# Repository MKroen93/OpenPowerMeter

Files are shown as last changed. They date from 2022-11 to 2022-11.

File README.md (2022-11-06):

# OpenPowerMeter
An open source power meter design including hardware and software

This is an open source power meter design. It is compatible with the **YHDC SCT-013-000** current clamp to measure AC mains current without contact. Optionally, 3 phase mains voltage can be measured by connecting it to the bottom screw terminal. The PCB is designed to fit into the Bopla CNC 87.5 DIN rail casing and consists on a lower and upper half of hardware which fit together through 2.54 mm pinheaders.

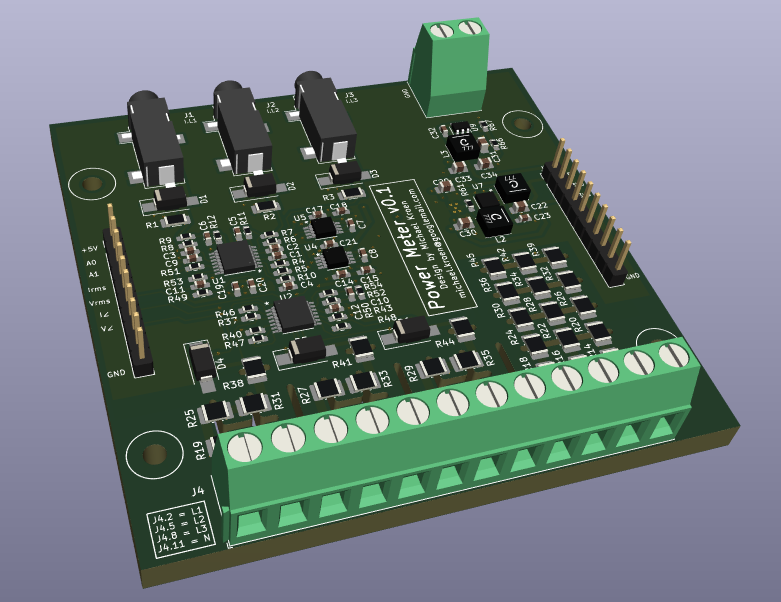
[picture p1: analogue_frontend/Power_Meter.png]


The lower part contains the analog frontend for converting the input signals to true rms values and for converting the input waveforms to a rectangular 3.3V output signal which can be used to detect the phase using a simple timer.

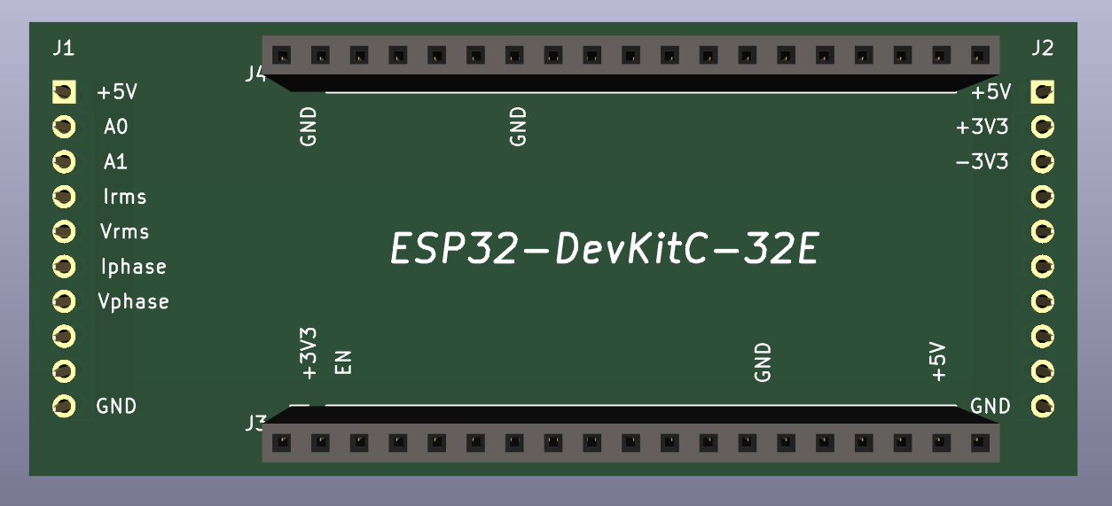
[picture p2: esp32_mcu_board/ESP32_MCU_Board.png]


The upper part contains the MCU (ESP32) and ADC and is not yet finished.

**Please note:** This project is currently in early development and not yet tested or ready to be used.

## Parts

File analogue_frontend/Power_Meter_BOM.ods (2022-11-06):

C:\Users\Michael\Documents\KiCAD\Power_Meter\Power_Meter.kicad_sch
05.11.2022 15:04:58
Eeschema (6.0.8)
C:\Program Files\KiCad\6.0\bin\scripting\plugins/bom_csv_grouped_by_value.py
132
Qty | Reference(s) | Value | LibPart | Footprint | Grade | Part nr. | Voltage rating
16 | C1 C2 C3 C9 C10 C13 C14 C15 C16 C17 C18 C19 C20 C21 C23 C32 | 100n | Device:C | 0603 | X7R |  | 10V
3 | C4 C5 C6 | 1n | Device:C | 0603 | X7R |  | 6.3V
4 | C7 C8 C11 C12 | 1µ | Device:C | 0603 | X7R |  | 6.3V
3 | C22 C29 C30 | 10µ | Device:C | 0805 | X7R |  | 10V
4 | C24 C25 C33 C34 | 22µ | Device:C | 0805 | X7R |  | 10V
3 | C26 C27 C28 | 10n | Device:C | 0603 | X7R |  | 10V
1 | C31 | 2µ2 | Device:C | 0805 |  |  | 35V
1 | C35 | 10µ | Device:C | 0805 | X5R |  | 35V
6 | D1 D2 D3 D4 D5 D6 | SMAJ5.0CA | Device:D_TVS | SMA
2 | D7 D8 | BAT54J | Diode:BAT54J | Diode_SMD:D_SOD-323F
1 | D9 | MM5Z6V8T1G | Diode:MM5Zxx | Diode_SMD:D_SOD-523
3 | J1 J2 J3 | AudioJack3 | Connector:AudioJack3 | Footprints:Jack_3.5mm_CUI_SJ-3523-SMT_Horizontal
1 | J4 | Screw_Terminal_01x12 | Connector:Screw_Terminal_01x12 | TerminalBlock_Phoenix:TerminalBlock_Phoenix_MKDS-1,5-12-5.08_1x12_P5.08mm_Horizontal
1 | J5 | Screw_Terminal_01x02 | Connector:Screw_Terminal_01x02 | TerminalBlock_Phoenix:TerminalBlock_Phoenix_MKDS-1,5-2-5.08_1x02_P5.08mm_Horizontal
2 | J6 J7 | Conn_01x10 | Connector_Generic:Conn_01x10 | Connector_PinHeader_2.54mm:PinHeader_1x10_P2.54mm_Vertical
2 | L1 L2 | 4µ7 | Device:L | Footprints:L_Coilcraft_XxL4020 |  | XFL4020-472ME_
1 | L3 | 10µ | Device:L | Footprints:L_Coilcraft_XxL4020 |  | XAL4040-103ME_
1 | Q1 | SISS73DN | SISS73DN:SISS73DN | Footprints:Vishay_PowerPAK_1212-8_Single
3 | R1,R2,R3 | 20 | Device:R | 1206
3 | R4 R6 R8 | 22k | Device:R | 0603
8 | R5 R7 R9 R10 R11 R12 R56 R59 | 47k | Device:R | 0603
30 | R13 R14 R15 R16 R17 R18 R19 R20 R21 R22 R23 R24 R25 R26 R27 R28 R29 R30 R31 R32 R33 R34 R35 R36 R38 R39 R41 R42 R44 R45 | 976k | Device:R | 1210
6 | R37 R40 R43 R46 R47 R48 | 15k | Device:R | 0603
2 | R49 R50 | 38k3 | Device:R | 0603
2 | R51 R52 | 169k | Device:R | 0603
2 | R53 R54 | 294k | Device:R | 0603
2 | R55 R58 | 1k | Device:R | 0603
2 | R57 R60 | 3k3 | Device:R | 0603
3 | R61 R63 R65 | 10k | Device:R | 0603
1 | R62 | 17k8 | Device:R | 0603
1 | R64 | 28k | Device:R | 0603
1 | R66 | 100k | Device:R | 0603
1 | R67 | 13k7 | Device:R | 0603
1 | R68 | 4k7 | Device:R | 0603
2 | U1 U2 | ADA4851-4 | ADA4851-4_multipart:ADA4851-4 | Footprints:ADA4851-4YRUZ
1 | U3 | ADG659 | ADG659_multipart:ADG659 | Footprints:ADG659YRUZ
2 | U4 U5 | LTC1966CMS8 | LTC1966:LTC1966CMS8 | Footprints:LTC1966CMS8
1 | U6 | ADA4851-2 | ADA4851-2_multipart:ADA4851-2 | Footprints:ADA4851-2YRMZ
1 | U7 | TPS65133DPDR | TPS65133:TPS65133DPDR | Footprints:TPS65133DPDR
1 | U8 | TPS7A3901DSCR | TPS7A39:TPS7A3901DSCR | Footprints:TPS7A3901DSCR
1 | U9 | PLMR51420XDDCR | LMR51420:PLMR51420XDDCT | Footprints:PLMR51420XDDCT
132

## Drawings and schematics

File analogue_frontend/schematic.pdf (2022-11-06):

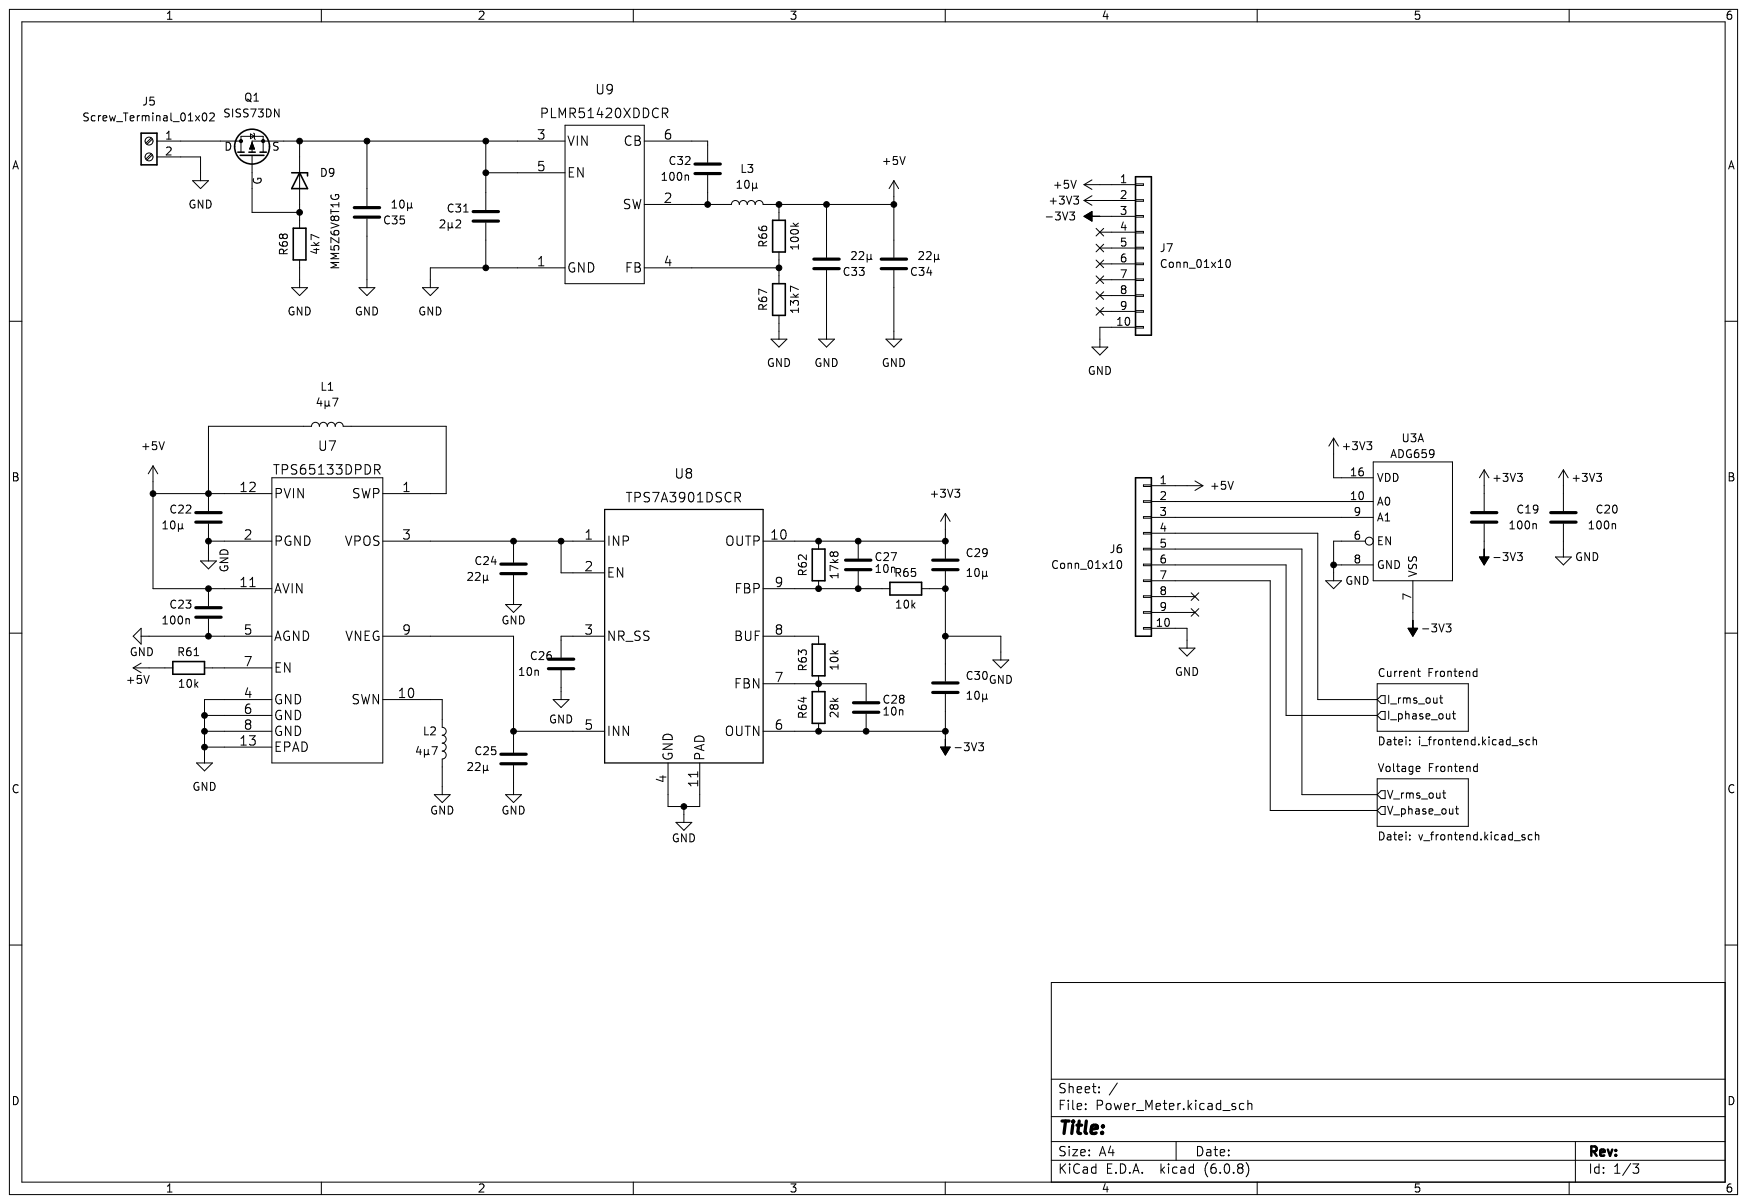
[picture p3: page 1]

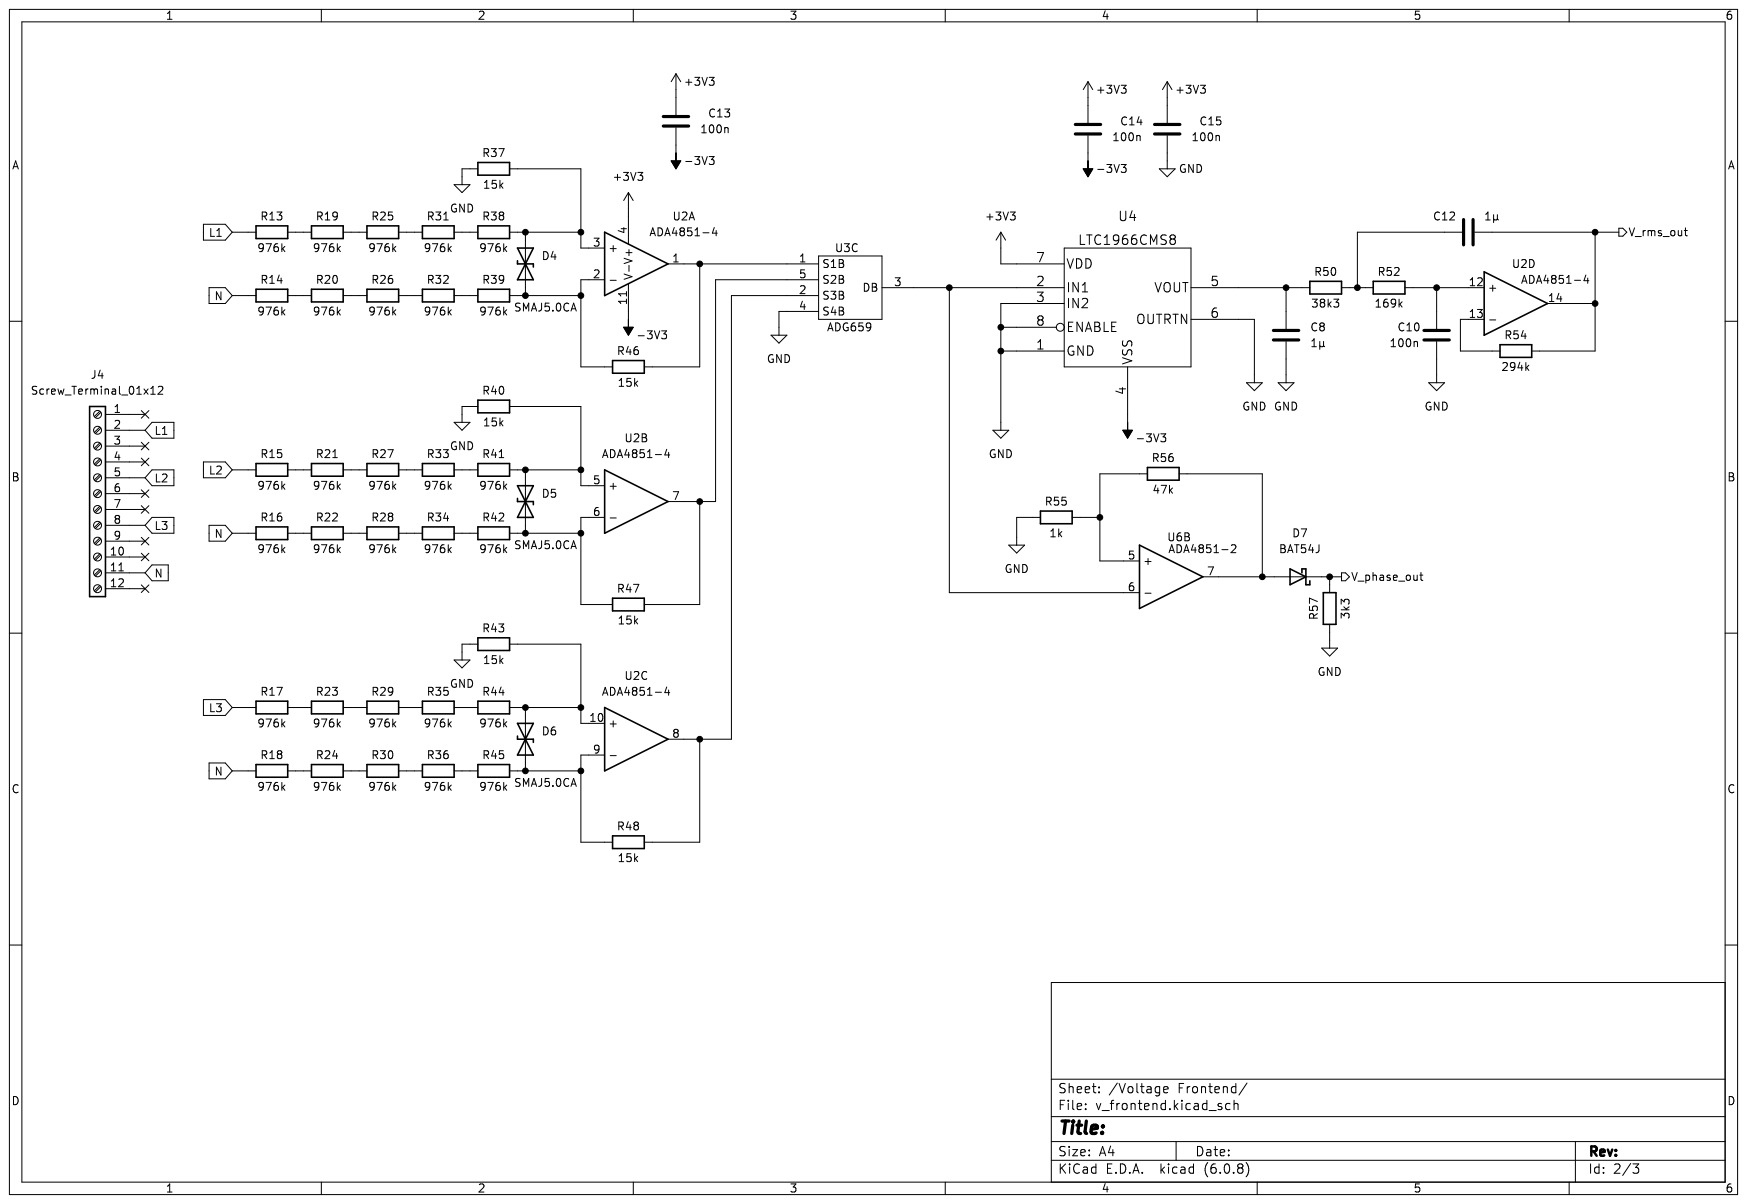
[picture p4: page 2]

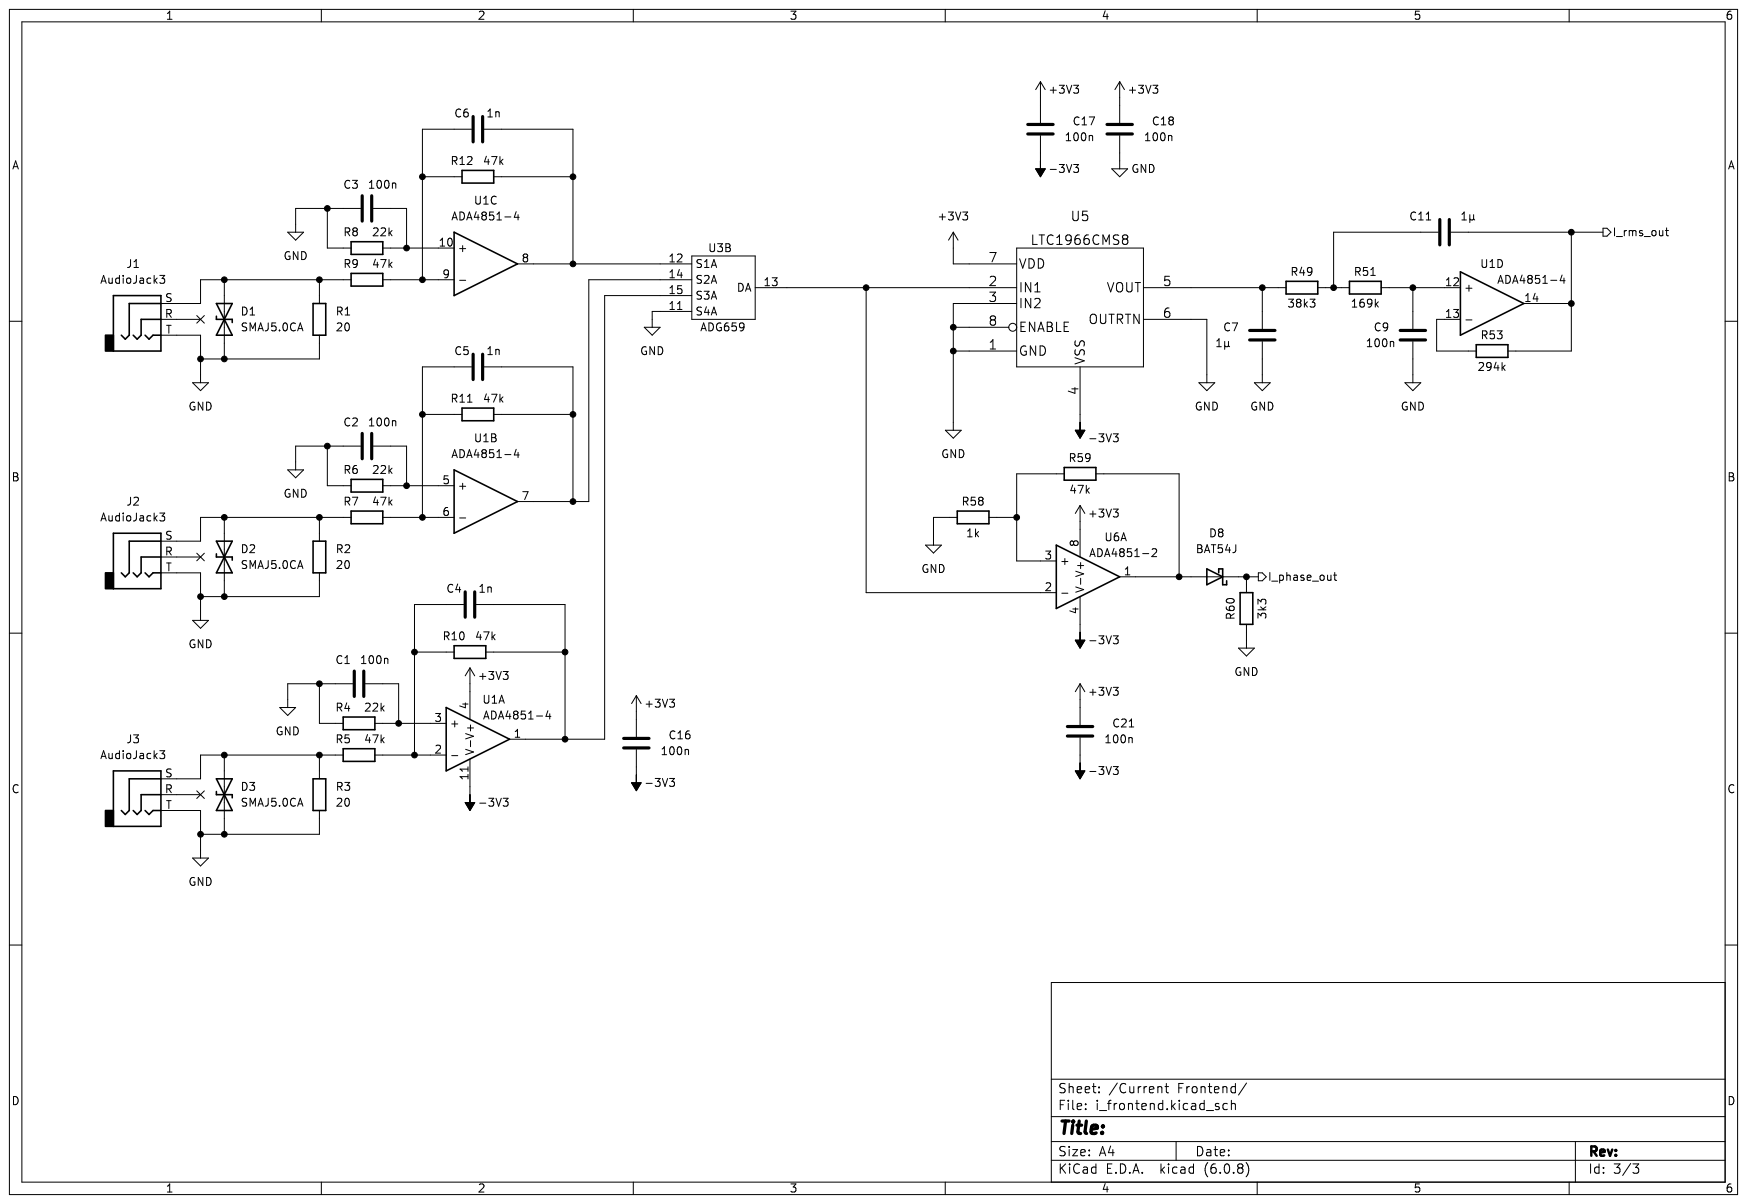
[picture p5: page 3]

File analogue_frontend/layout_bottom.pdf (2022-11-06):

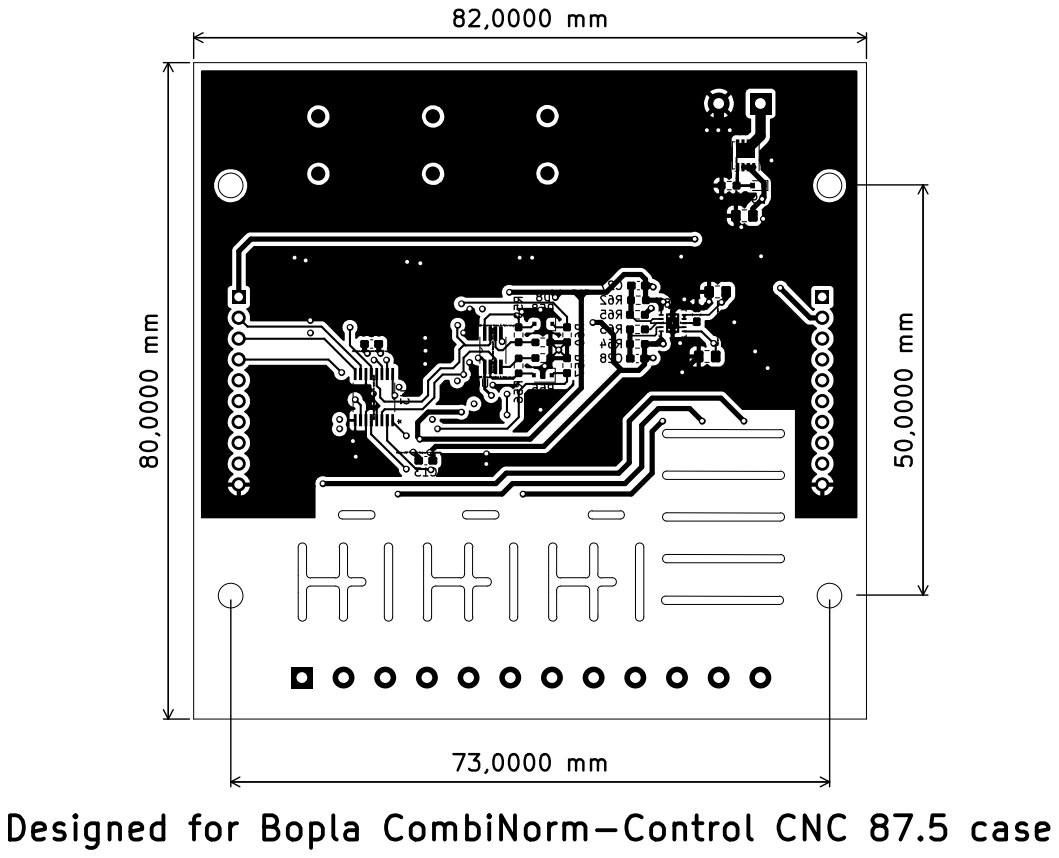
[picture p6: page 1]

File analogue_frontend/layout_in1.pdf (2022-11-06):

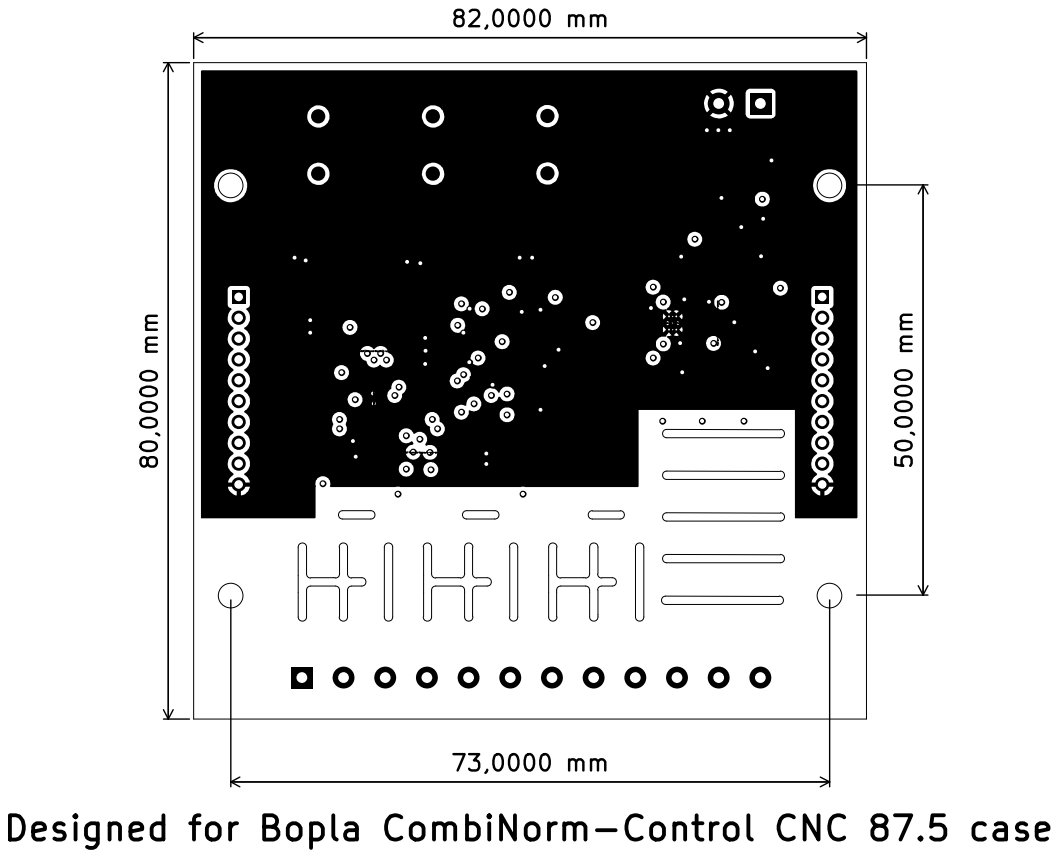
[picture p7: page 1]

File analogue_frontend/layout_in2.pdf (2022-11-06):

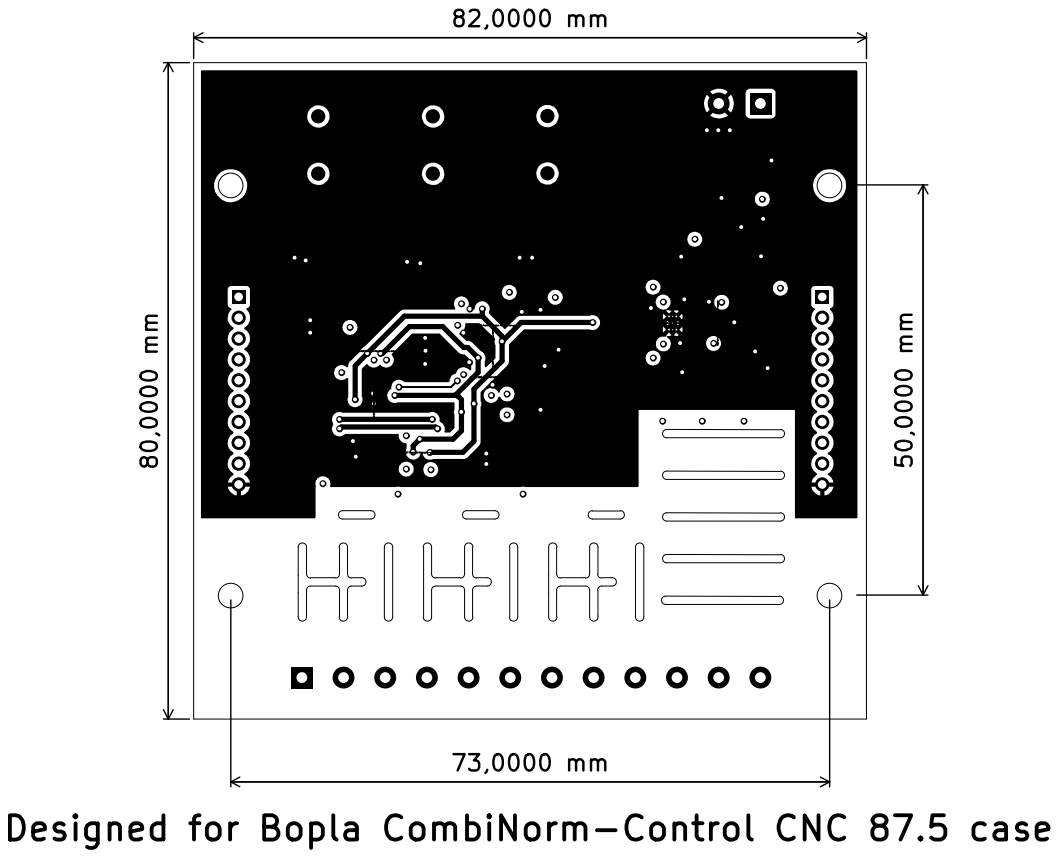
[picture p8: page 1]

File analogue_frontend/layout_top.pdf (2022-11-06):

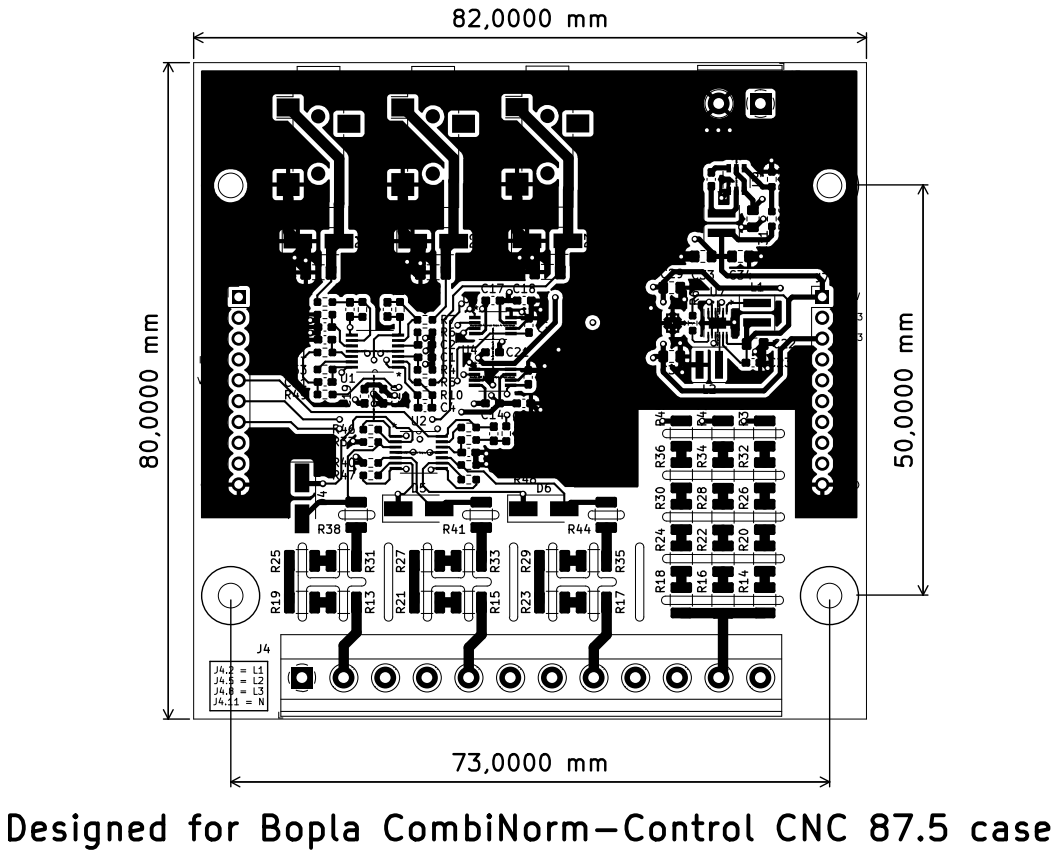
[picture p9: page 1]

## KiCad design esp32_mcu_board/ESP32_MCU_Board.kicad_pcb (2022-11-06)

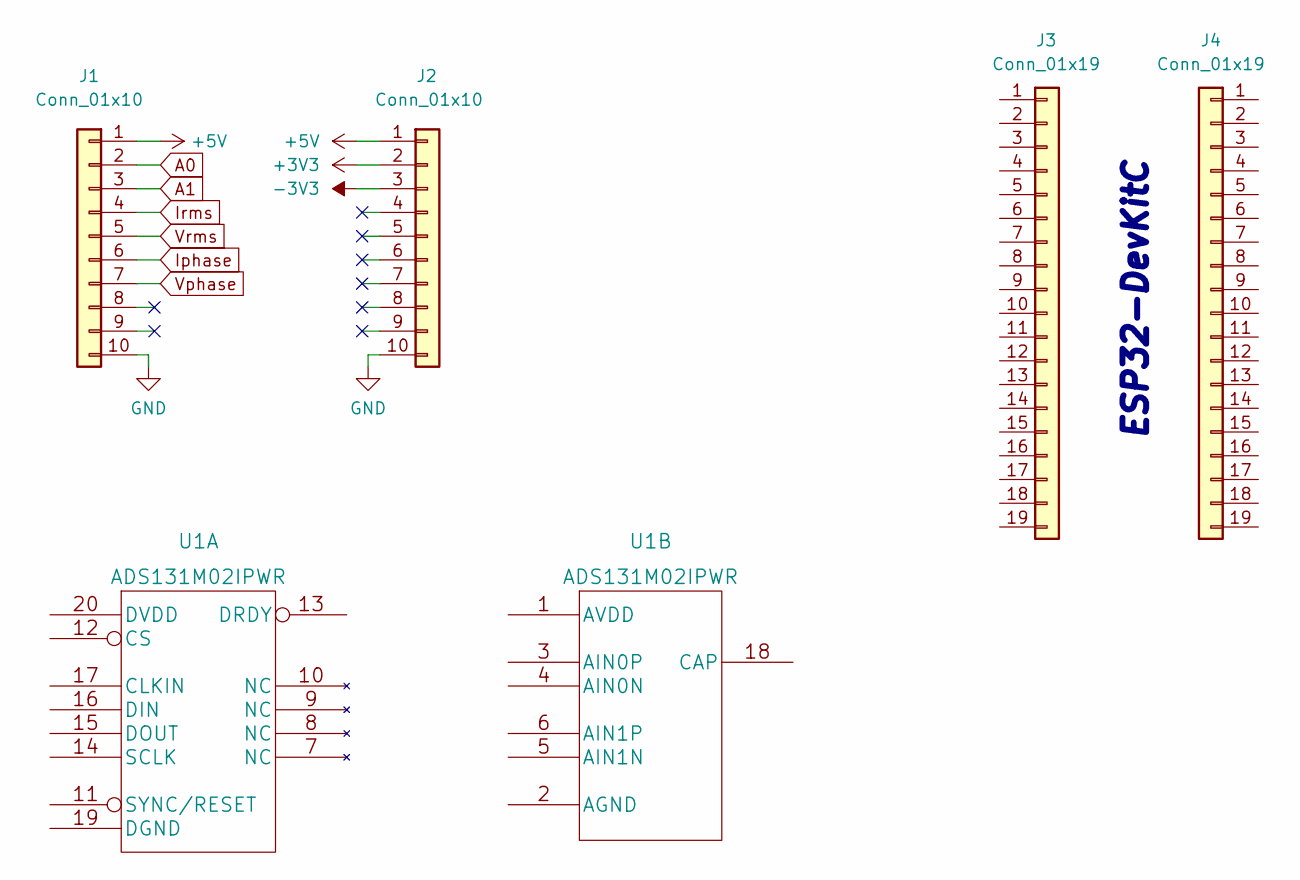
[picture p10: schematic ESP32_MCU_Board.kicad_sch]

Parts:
J1, J2: Conn_01x10; PinSocket_1x10_P2.54mm_Vertical
J3, J4: Conn_01x19; PinSocket_1x19_P2.54mm_Vertical
U1: ADS131M02IPWR

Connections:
+3V3: J2.2
+5V: J1.1, J2.1
-3V3: J2.3
A0: J1.2
A1: J1.3
GND: J1.10, J2.10
Iphase: J1.6
Irms: J1.4
Vphase: J1.7
Vrms: J1.5

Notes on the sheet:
ESP32-DevKitC

Board: 2 copper layers, 5 parts (2 on the bottom side), 2 nets, no tracks yet.

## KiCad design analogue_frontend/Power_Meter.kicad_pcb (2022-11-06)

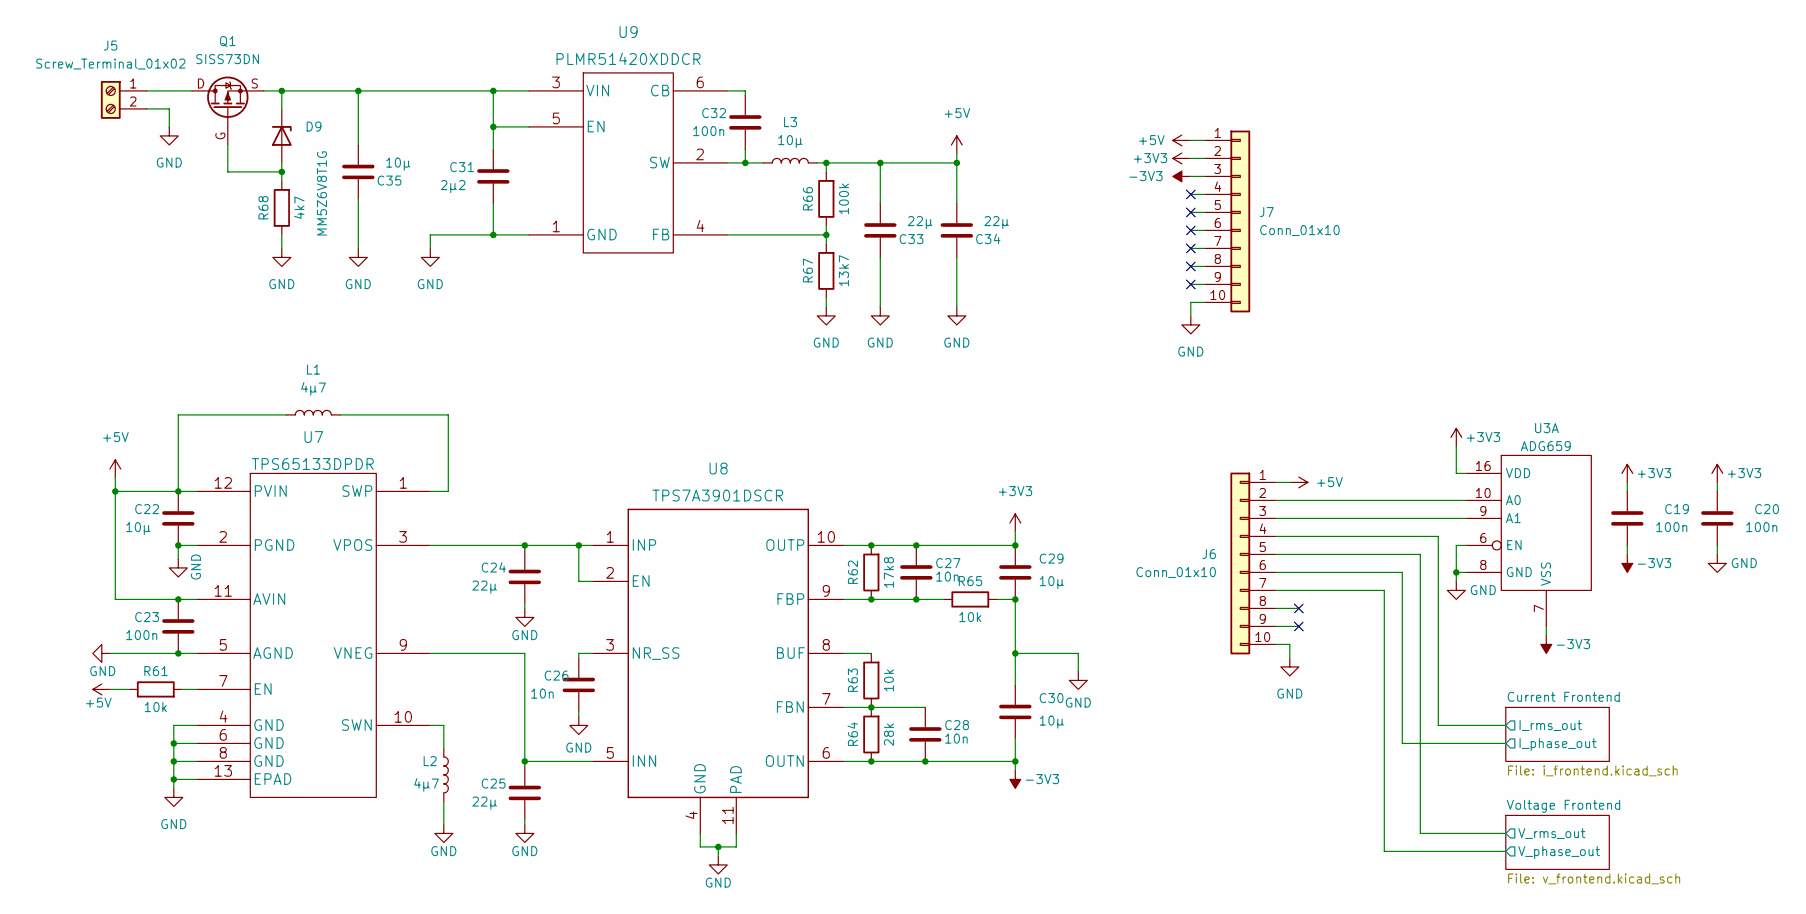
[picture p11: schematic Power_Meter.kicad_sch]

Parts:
C19, C23: 100n; C_0603_1608Metric_Pad1.08x0.95mm_HandSolder; Voltage rating 10V
C20: 100n; C_0603_1608Metric_Pad1.08x0.95mm_HandSolder; Voltage rating 6.3V
C22: 10µ; C_0805_2012Metric_Pad1.18x1.45mm_HandSolder; Voltage rating 10V
C24, C25, C33, C34: 22µ; C_0805_2012Metric_Pad1.18x1.45mm_HandSolder; Voltage rating 10V
C26: 10n; C_0603_1608Metric_Pad1.08x0.95mm_HandSolder; Voltage rating 10V
C27, C28: 10n; C_0603_1608Metric_Pad1.08x0.95mm_HandSolder; Voltage rating 6.3V
C29, C30: 10µ; C_0805_2012Metric_Pad1.18x1.45mm_HandSolder; Voltage rating 6.3V
C31: 2µ2; C_0805_2012Metric_Pad1.18x1.45mm_HandSolder; Voltage rating 35V
C32: 100n; C_0603_1608Metric_Pad1.08x0.95mm_HandSolder; Voltage rating 16V
C35: 10µ; C_0805_2012Metric_Pad1.18x1.45mm_HandSolder; Voltage rating 35V
D9: MM5Z6V8T1G; D_SOD-523
J5: Screw_Terminal_01x02; TerminalBlock_Phoenix_MKDS-1,5-2-5.08_1x02_P5.08mm_Horizont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
J6, J7: Conn_01x10; PinHeader_1x10_P2.54mm_Vertical
L1, L2: 4µ7; L_Coilcraft_XxL4020; Part nr. XFL4020-472ME_
L3: 10µ; L_Coilcraft_XxL4020; Part nr. XAL4040-103ME_
Q1: SISS73DN; Vishay_PowerPAK_1212-8_Single
R61, R63, R65: 10k; R_0603_1608Metric_Pad0.98x0.95mm_HandSolder
R62: 17k8; R_0603_1608Metric_Pad0.98x0.95mm_HandSolder
R64: 28k; R_0603_1608Metric_Pad0.98x0.95mm_HandSolder
R66: 100k; R_0603_1608Metric_Pad0.98x0.95mm_HandSolder
R67: 13k7; R_0603_1608Metric_Pad0.98x0.95mm_HandSolder
R68: 4k7; R_0603_1608Metric_Pad0.98x0.95mm_HandSolder
U3: ADG659; ADG659YRUZ
U7: TPS65133DPDR
U8: TPS7A3901DSCR
U9: PLMR51420XDDCR; PLMR51420XDDCT

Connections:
+3V3: C19.1, C20.1, C27.1, C29.1, J7.2, R62.2, U3.16 (VDD), U8.10 (OUTP); also elsewhere on the board
+5V: C22.1, C23.1, C33.2, C34.2, J6.1, J7.1, L1.1, L3.2, R61.1, R66.2, U7.11 (AVIN), U7.12 (PVIN)
-3V3: C19.2, C28.2, C30.2, J7.3, R64.1, U3.7 (VSS), U8.6 (OUTN); also elsewhere on the board
/Current Frontend/I_phase_out: J6.6; also elsewhere on the board
/Current Frontend/I_rms_out: J6.4; also elsewhere on the board
/Voltage Frontend/V_phase_out: J6.7; also elsewhere on the board
/Voltage Frontend/V_rms_out: J6.5; also elsewhere on the board
GND: C20.2, C22.2, C23.2, C24.2, C25.2, C26.2, C29.2, C30.1, C31.2, C33.1, C34.1, C35.1, J5.2, J6.10, J7.10, L2.2, R65.2, R67.1, R68.1, U3.6 (EN), U3.8 (GND), U7.2 (PGND), U7.4 (GND), U7.5 (AGND), U7.6 (GND), U7.8 (GND), U7.13 (EPAD), U8.4 (GND), U8.11 (PAD), U9.1 (GND); also elsewhere on the board
unnamed: C24.1, U7.3 (VPOS), U8.1 (INP), U8.2 (EN)
unnamed: C25.1, U7.9 (VNEG), U8.5 (INN)
unnamed: C26.1, U8.3 (NR_SS)
unnamed: C27.2, R62.1, R65.1, U8.9 (FBP)
unnamed: C28.1, R63.1, R64.2, U8.7 (FBN)
unnamed: C31.1, C35.2, D9.1 (K), Q1.S, U9.3 (VIN), U9.5 (EN)
unnamed: C32.1, U9.6 (CB)
unnamed: C32.2, L3.1, U9.2 (SW)
unnamed: D9.2 (A), Q1.G, R68.2
unnamed: J5.1, Q1.D
unnamed: J6.2, U3.10 (A0)
unnamed: J6.3, U3.9 (A1)
unnamed: L1.2, U7.1 (SWP)
unnamed: L2.1, U7.10 (SWN)
unnamed: R61.2, U7.7 (EN)
unnamed: R63.2, U8.8 (BUF)
unnamed: R66.1, R67.2, U9.4 (FB)

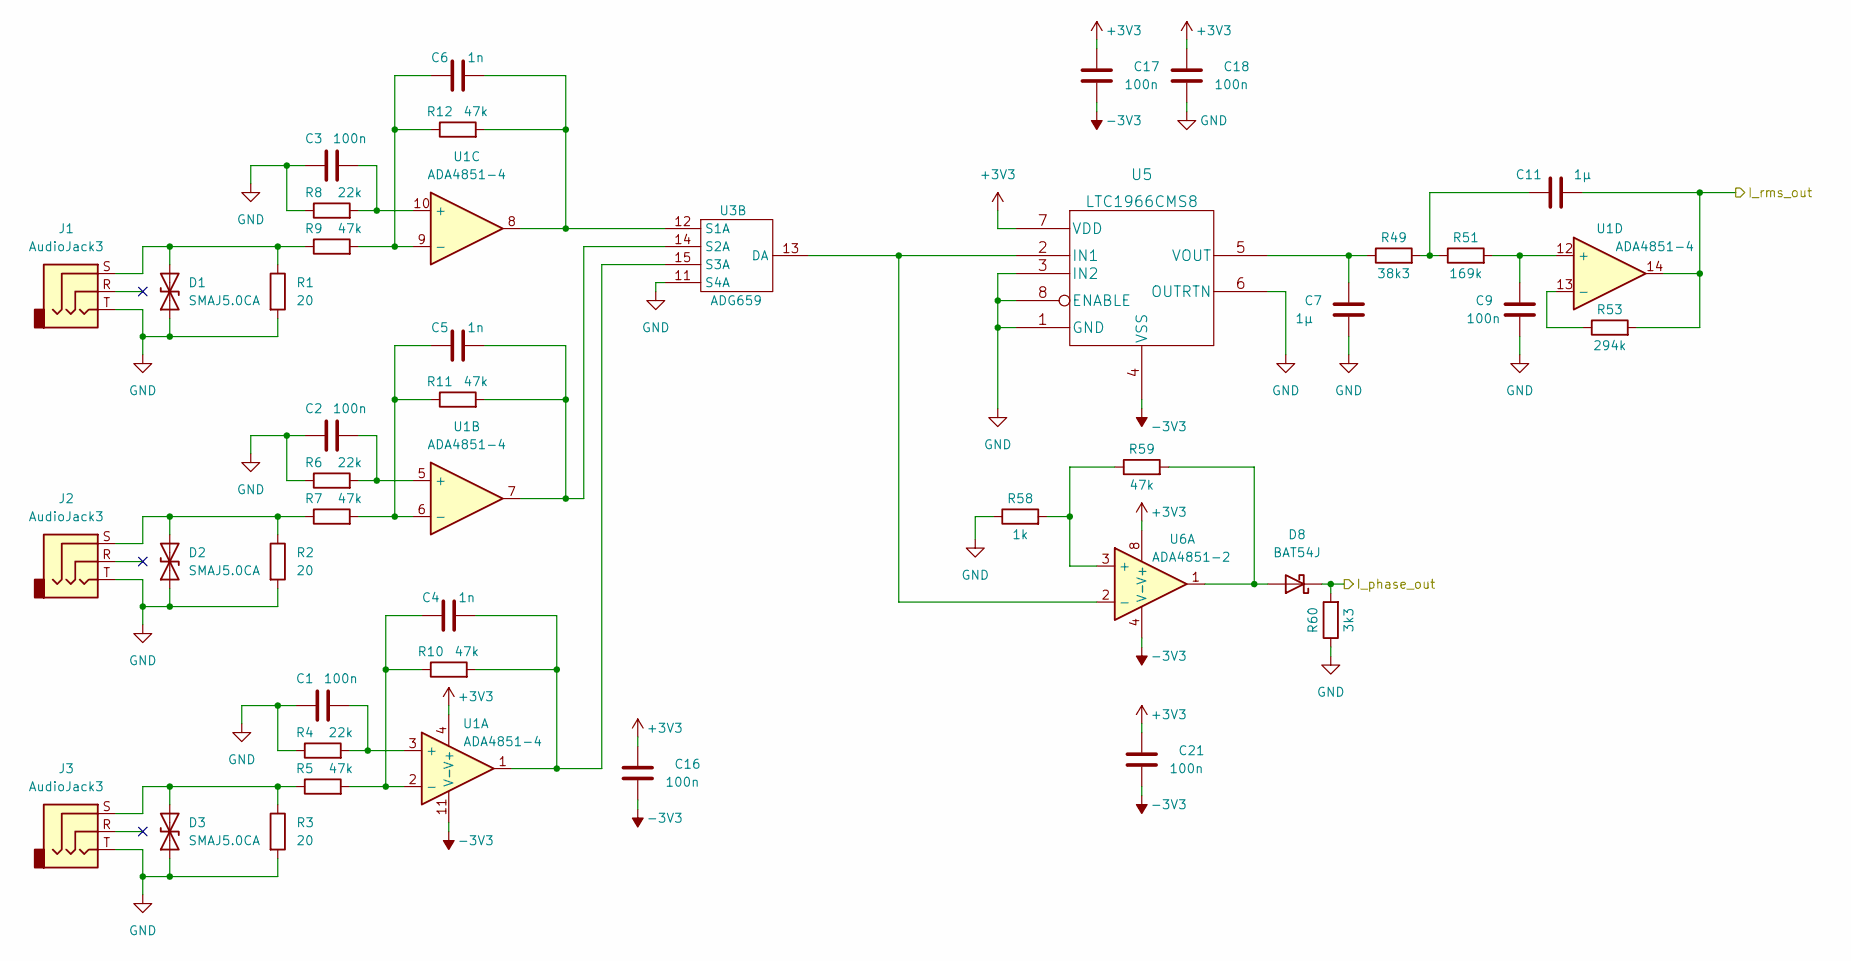
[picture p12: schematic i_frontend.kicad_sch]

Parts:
C1, C2, C3, C9, C18: 100n; C_0603_1608Metric_Pad1.08x0.95mm_HandSolder; Voltage rating 6.3V
C4, C5, C6: 1n; C_0603_1608Metric_Pad1.08x0.95mm_HandSolder; Voltage rating 6.3V
C7, C11: 1µ; C_0603_1608Metric_Pad1.08x0.95mm_HandSolder; Voltage rating 6.3V
C16, C17, C21: 100n; C_0603_1608Metric_Pad1.08x0.95mm_HandSolder; Voltage rating 10V
D1, D2, D3: SMAJ5.0CA; D_SMA_Handsoldering
D8: BAT54J; D_SOD-323F
J1, J2, J3: AudioJack3; Jack_3.5mm_CUI_SJ-3523-SMT_Horizontal
R1, R2, R3: 20; R_1206_3216Metric_Pad1.30x1.75mm_HandSolder
R4, R6, R8: 22k; R_0603_1608Metric_Pad0.98x0.95mm_HandSolder
R5, R7, R9, R10, R11, R12, R59: 47k; R_0603_1608Metric_Pad0.98x0.95mm_HandSolder
R49: 38k3; R_0603_1608Metric_Pad0.98x0.95mm_HandSolder
R51: 169k; R_0603_1608Metric_Pad0.98x0.95mm_HandSolder
R53: 294k; R_0603_1608Metric_Pad0.98x0.95mm_HandSolder
R58: 1k; R_0603_1608Metric_Pad0.98x0.95mm_HandSolder
R60: 3k3; R_0603_1608Metric_Pad0.98x0.95mm_HandSolder
U1: ADA4851-4; ADA4851-4YRUZ
U3: ADG659; ADG659YRUZ
U5: LTC1966CMS8
U6: ADA4851-2; ADA4851-2YRMZ

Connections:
+3V3: C16.1, C17.1, C18.1, C21.1, U1.4 (V+), U5.7 (VDD), U6.8 (V+); also elsewhere on the board
-3V3: C16.2, C17.2, C21.2, U1.11 (V-), U5.4 (VSS), U6.4 (V-); also elsewhere on the board
/Current Frontend/I_phase_out: D8.1 (K), R60.2; also elsewhere on the board
/Current Frontend/I_rms_out: C11.2, R53.2, U1.14; also elsewhere on the board
GND: C1.1, C2.1, C3.1, C7.2, C9.2, C18.2, D1.1 (A1), D2.1 (A1), D3.1 (A1), J1.T, J2.T, J3.T, R1.2, R2.2, R3.2, R4.1, R6.1, R8.1, R58.1, R60.1, U3.11 (S4A), U5.1 (GND), U5.3 (IN2), U5.6 (OUTRTN), U5.8 (ENABLE); also elsewhere on the board
unnamed: C1.2, R4.2, U1.3 (+)
unnamed: C2.2, R6.2, U1.5 (+)
unnamed: C3.2, R8.2, U1.10 (+)
unnamed: C4.1, R5.2, R10.1, U1.2 (-)
unnamed: C4.2, R10.2, U1.1, U3.15 (S3A)
unnamed: C5.1, R7.2, R11.1, U1.6 (-)
unnamed: C5.2, R11.2, U1.7, U3.14 (S2A)
unnamed: C6.1, R9.2, R12.1, U1.9 (-)
unnamed: C6.2, R12.2, U1.8, U3.12 (S1A)
unnamed: C7.1, R49.1, U5.5 (VOUT)
unnamed: C9.1, R51.2, U1.12 (+)
unnamed: C11.1, R49.2, R51.1
unnamed: D1.2 (A2), J1.S, R1.1, R9.1
unnamed: D2.2 (A2), J2.S, R2.1, R7.1
unnamed: D3.2 (A2), J3.S, R3.1, R5.1
unnamed: D8.2 (A), R59.2, U6.1
unnamed: R53.1, U1.13 (-)
unnamed: R58.2, R59.1, U6.3 (+)
unnamed: U3.13 (DA), U5.2 (IN1), U6.2 (-)

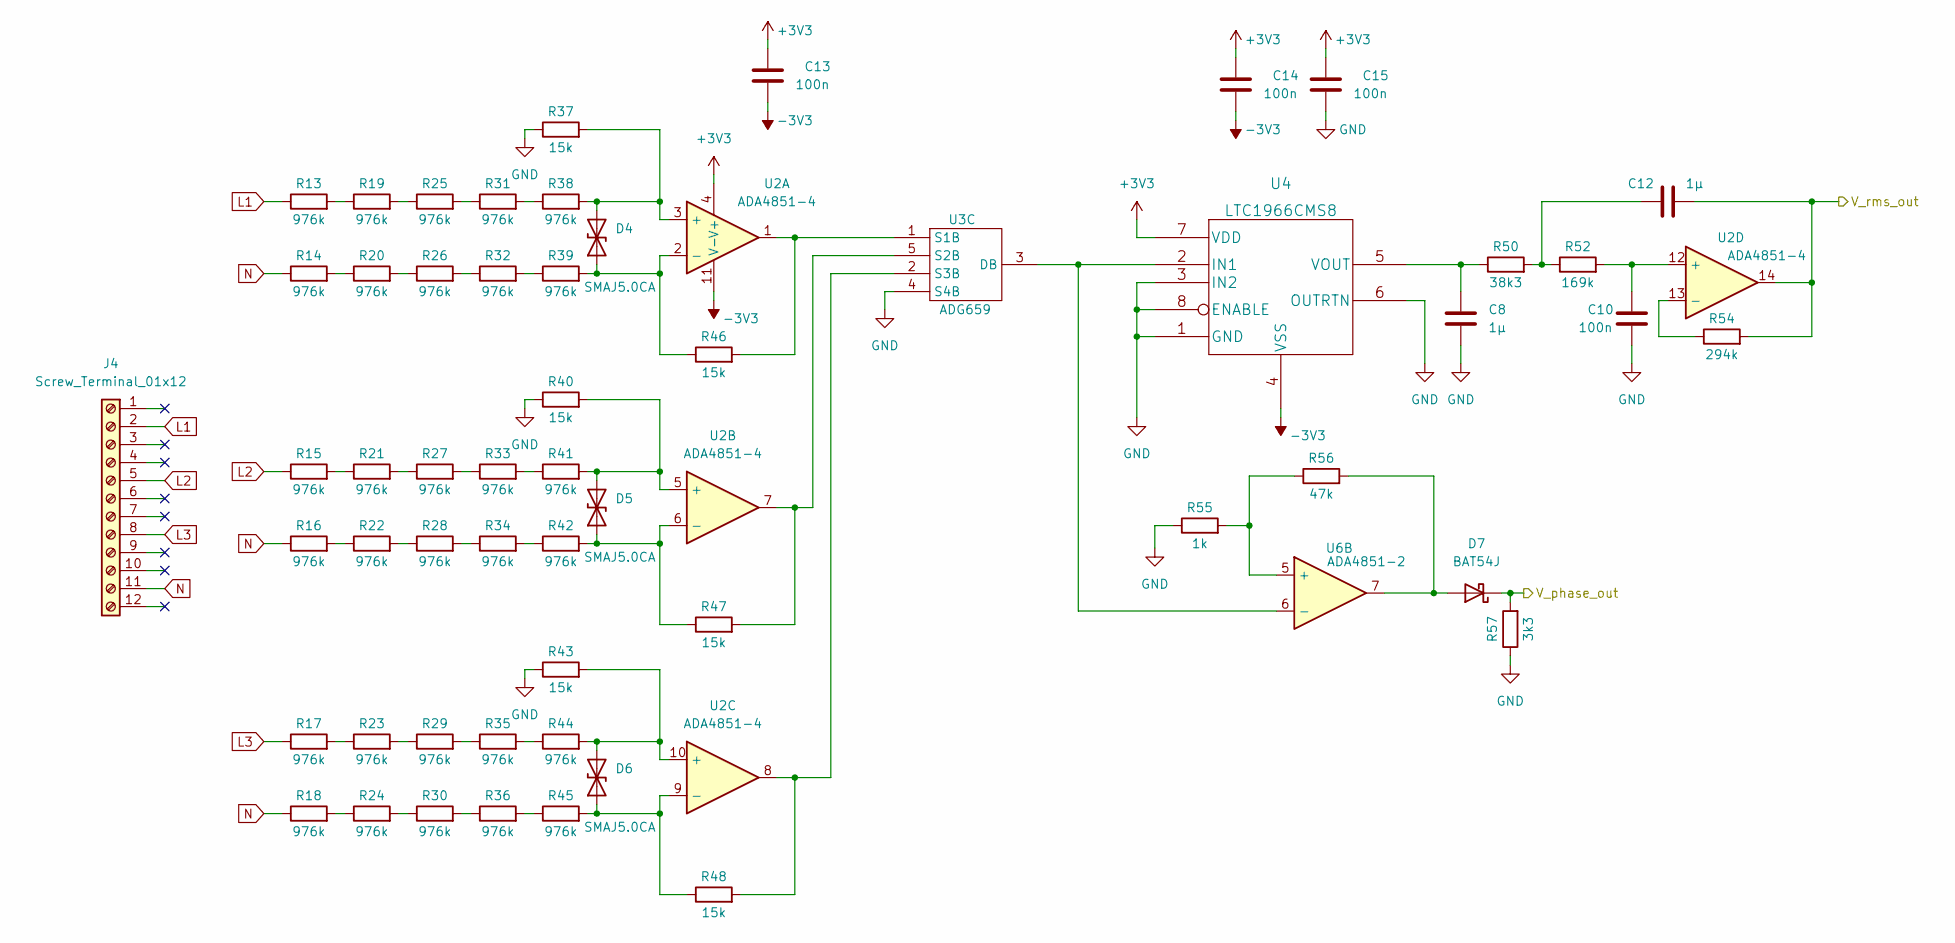
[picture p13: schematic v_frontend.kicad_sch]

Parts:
C8, C12: 1µ; C_0603_1608Metric_Pad1.08x0.95mm_HandSolder; Voltage rating 6.3V
C10, C15: 100n; C_0603_1608Metric_Pad1.08x0.95mm_HandSolder; Voltage rating 6.3V
C13, C14: 100n; C_0603_1608Metric_Pad1.08x0.95mm_HandSolder; Voltage rating 10V
D4, D5, D6: SMAJ5.0CA; D_SMA_Handsoldering
D7: BAT54J; D_SOD-323F
J4: Screw_Terminal_01x12; TerminalBlock_Phoenix_MKDS-1,5-12-5.08_1x12_P5.08mm_Horizon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
R13, R14, R15, R16, R17, R18, R19, R20, R21, R22, R23, R24, R25, R26, R27, R28, R29, R30, R31, R32, R33, R34, R35, R36, R38, R39, R41, R42, R44, R45: 976k; R_1210_3225Metric_Pad1.30x2.65mm_HandSolder
R37, R40, R43, R46, R47, R48: 15k; R_0603_1608Metric_Pad0.98x0.95mm_HandSolder
R50: 38k3; R_0603_1608Metric_Pad0.98x0.95mm_HandSolder
R52: 169k; R_0603_1608Metric_Pad0.98x0.95mm_HandSolder
R54: 294k; R_0603_1608Metric_Pad0.98x0.95mm_HandSolder
R55: 1k; R_0603_1608Metric_Pad0.98x0.95mm_HandSolder
R56: 47k; R_0603_1608Metric_Pad0.98x0.95mm_HandSolder
R57: 3k3; R_0603_1608Metric_Pad0.98x0.95mm_HandSolder
U2: ADA4851-4; ADA4851-4YRUZ
U3: ADG659; ADG659YRUZ
U4: LTC1966CMS8
U6: ADA4851-2; ADA4851-2YRMZ

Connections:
+3V3: C13.1, C14.1, C15.1, U2.4 (V+), U4.7 (VDD); also elsewhere on the board
-3V3: C13.2, C14.2, U2.11 (V-), U4.4 (VSS); also elsewhere on the board
/Voltage Frontend/V_phase_out: D7.1 (K), R57.2; also elsewhere on the board
/Voltage Frontend/V_rms_out: C12.2, R54.2, U2.14; also elsewhere on the board
GND: C8.2, C10.2, C15.2, R37.1, R40.1, R43.1, R55.1, R57.1, U3.4 (S4B), U4.1 (GND), U4.3 (IN2), U4.6 (OUTRTN), U4.8 (ENABLE); also elsewhere on the board
L1: J4.2, R13.1
L2: J4.5, R15.1
L3: J4.8, R17.1
N: J4.11, R14.1, R16.1, R18.1
unnamed: C8.1, R50.1, U4.5 (VOUT)
unnamed: C10.1, R52.2, U2.12 (+)
unnamed: C12.1, R50.2, R52.1
unnamed: D4.1 (A1), R39.2, R46.1, U2.2 (-)
unnamed: D4.2 (A2), R37.2, R38.2, U2.3 (+)
unnamed: D5.1 (A1), R42.2, R47.1, U2.6 (-)
unnamed: D5.2 (A2), R40.2, R41.2, U2.5 (+)
unnamed: D6.1 (A1), R45.2, R48.1, U2.9 (-)
unnamed: D6.2 (A2), R43.2, R44.2, U2.10 (+)
unnamed: D7.2 (A), R56.2, U6.7
unnamed: R13.2, R19.1
unnamed: R14.2, R20.1
unnamed: R15.2, R21.1
unnamed: R16.2, R22.1
unnamed: R17.2, R23.1
unnamed: R18.2, R24.1
unnamed: R19.2, R25.1
unnamed: R20.2, R26.1
unnamed: R21.2, R27.1
unnamed: R22.2, R28.1
unnamed: R23.2, R29.1
unnamed: R24.2, R30.1
unnamed: R25.2, R31.1
unnamed: R26.2, R32.1
unnamed: R27.2, R33.1
unnamed: R28.2, R34.1
unnamed: R29.2, R35.1
unnamed: R30.2, R36.1
unnamed: R31.2, R38.1
unnamed: R32.2, R39.1
unnamed: R33.2, R41.1
unnamed: R34.2, R42.1
unnamed: R35.2, R44.1
unnamed: R36.2, R45.1
unnamed: R46.2, U2.1, U3.1 (S1B)
unnamed: R47.2, U2.7, U3.5 (S2B)
unnamed: R48.2, U2.8, U3.2 (S3B)
unnamed: R54.1, U2.13 (-)
unnamed: R55.2, R56.1, U6.5 (+)
unnamed: U3.3 (DB), U4.2 (IN1), U6.6 (-)

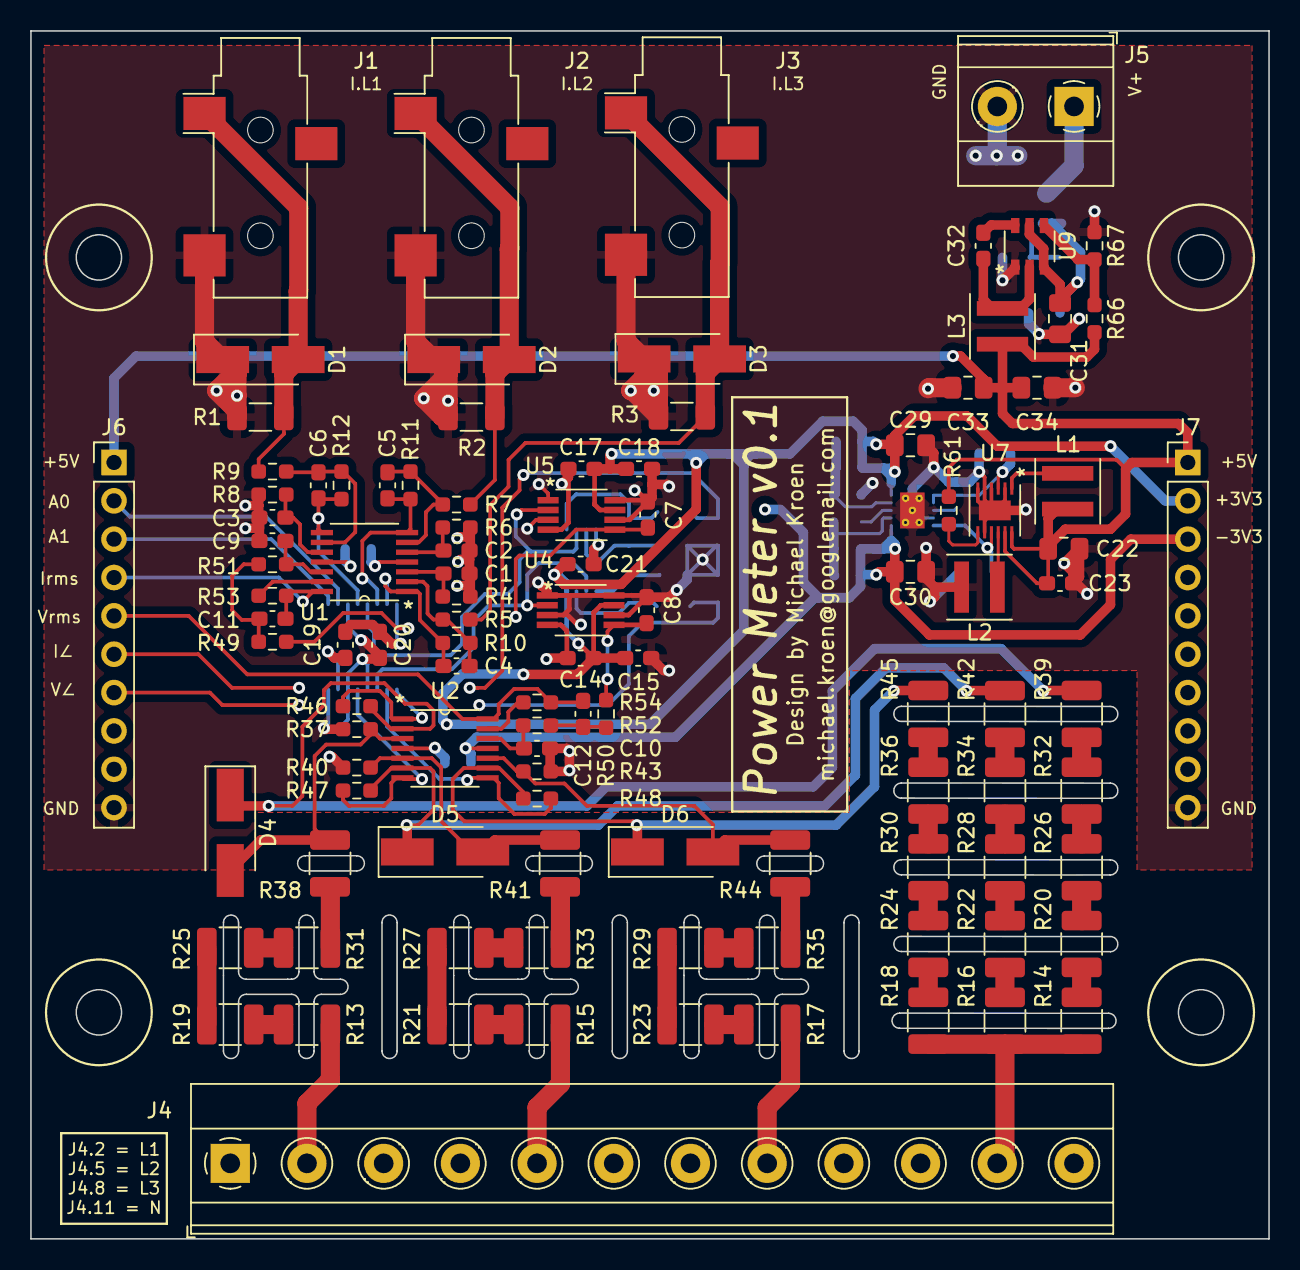
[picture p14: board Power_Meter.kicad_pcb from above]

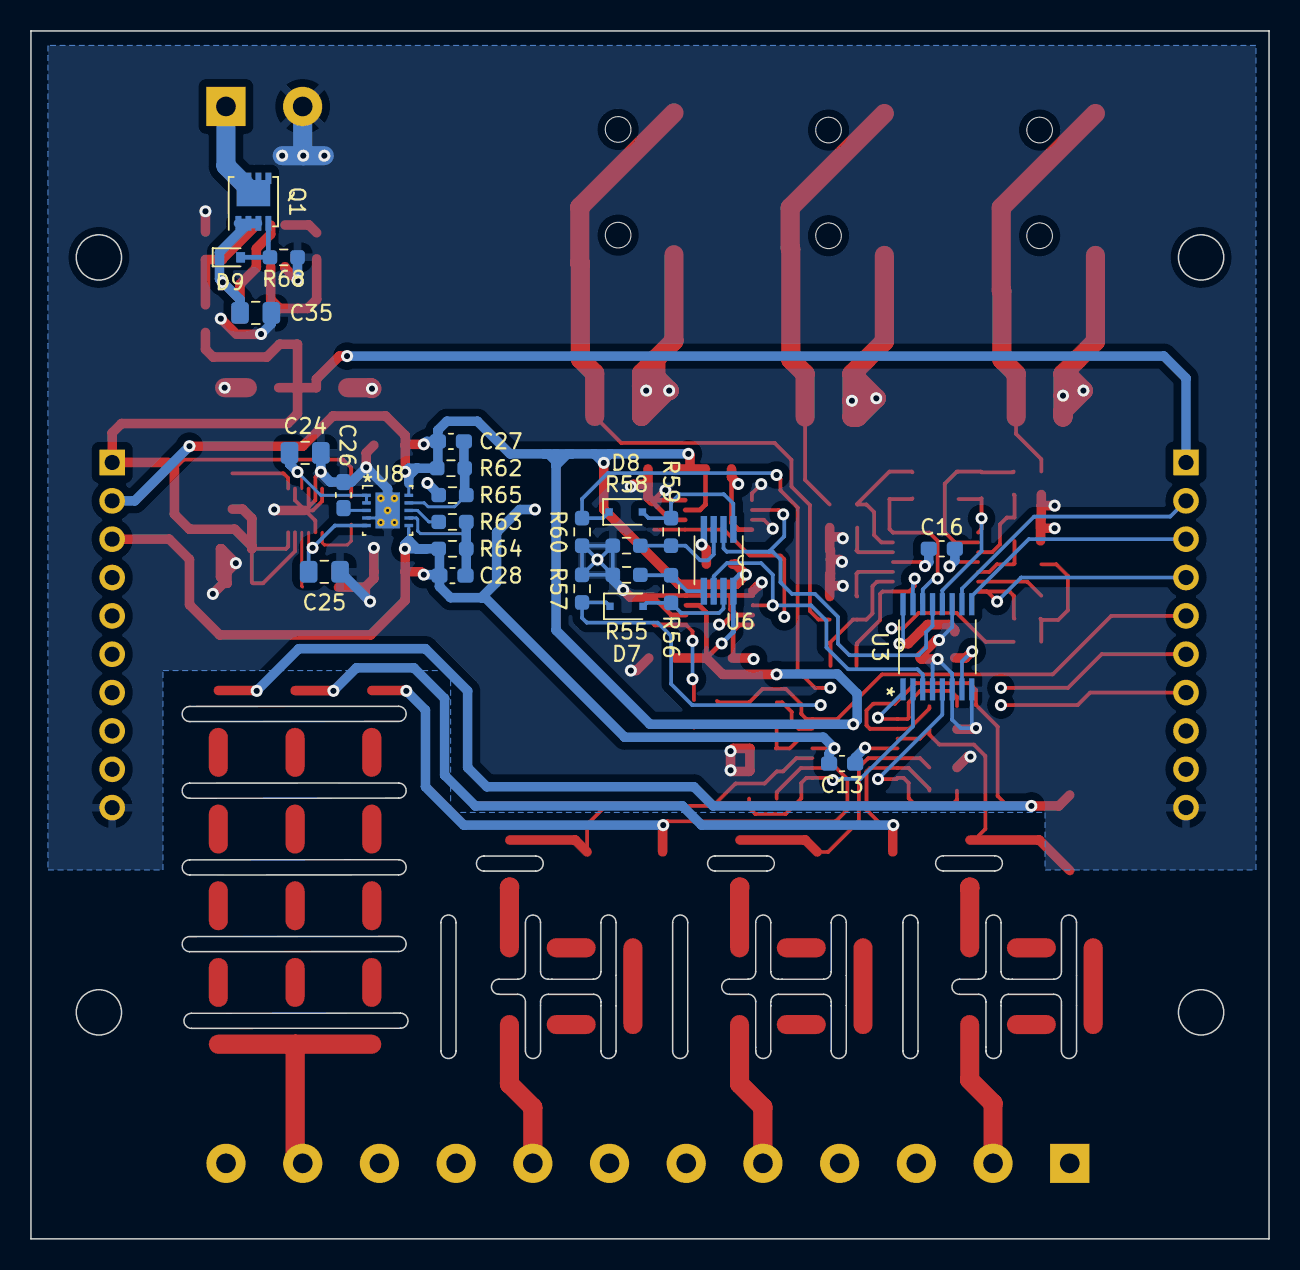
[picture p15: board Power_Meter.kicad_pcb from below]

Board: 4 copper layers, 82.0 x 80.0 mm, 132 parts (26 on the bottom side), 88 nets.

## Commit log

2022-11-06 Adding initial hardware design revision
    [Power_Meter-B_Cu.gbr, Power_Meter-B_Mask.gbr, Power_Meter-B_Paste.gbr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]
2022-11-06 Adding .pdf exports
    [Power_Meter.kicad_pcb, Power_Meter.kicad_sch]
2022-11-06 Changing folder structure to destinguish analogue / digital part
    [Power_Meter-B_Cu.gbr, Power_Meter-B_Mask.gbr, Power_Meter-B_Paste.gbr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]
2022-11-06 Added ESP32 MCU board design (WiP)
    [ESP32_MCU_Board.kicad_pcb, ESP32_MCU_Board.kicad_sch]
2022-11-06 Added ESP32 MCU board to project description
    [ESP32_MCU_Board.kicad_pcb]
2022-11-06 Added ADS131M02IPWR ADC for MCU board to symbol and footprint library
    [ESP32_MCU_Board.kicad_pcb, ESP32_MCU_Board.kicad_sch]

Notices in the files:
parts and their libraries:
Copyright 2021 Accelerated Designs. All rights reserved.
